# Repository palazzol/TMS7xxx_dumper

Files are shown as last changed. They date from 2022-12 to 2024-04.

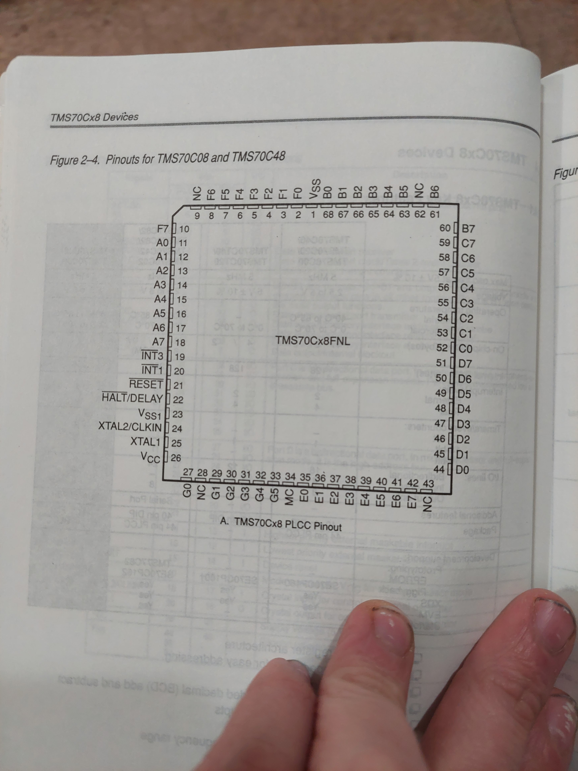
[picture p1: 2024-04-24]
images/latest databook excerpts/20230110_172906.jpg

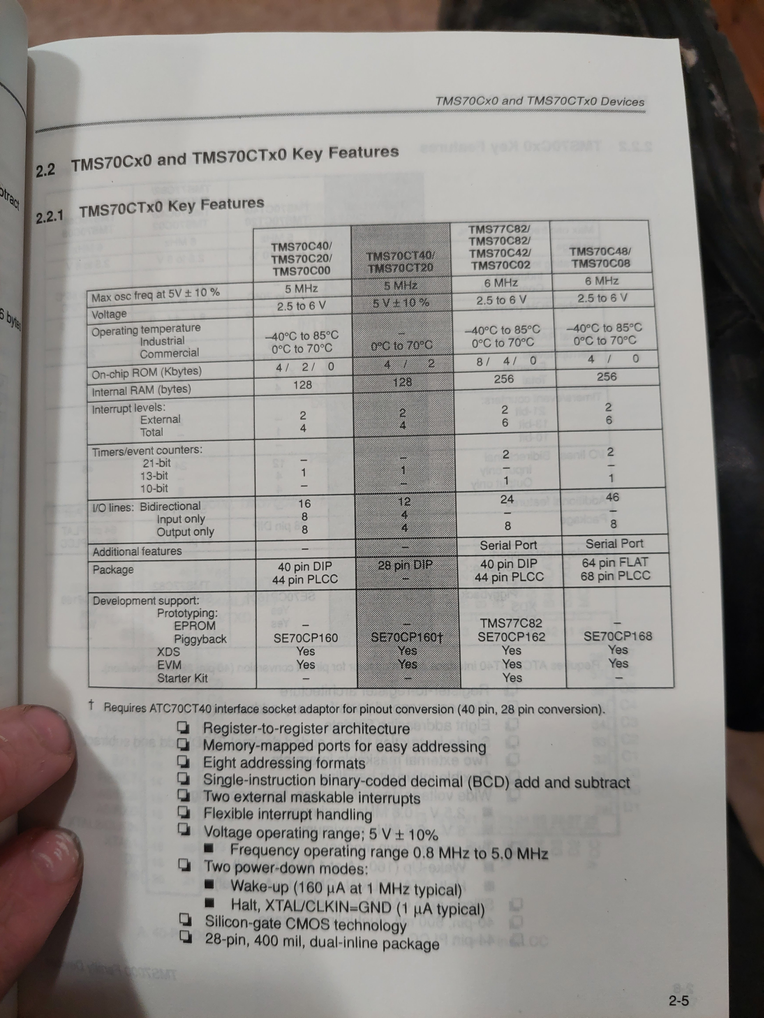
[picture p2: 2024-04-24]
images/latest databook excerpts/20230110_172813.jpg

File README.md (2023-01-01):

# Internal ROM dumper for TMS7xxx series chips

Texas Instruments made a series of chips based on the TMS7000 microprocessor, which can contain internal programs in mask ROM.
General Instrument / Microchip made versions of these chips as well (PIC7000 series).

In addition, at least one commercial IC with a different label is actually one of these internally.
For example, the CTS256A-AL2, which was sold at Radio Shack, is actually a PIC7041.

This design supports all known chips in the series, including:
PIC70XX, TMS70XX, TMS70XXX, TMS77XX, TMS70CXX, and TMS77CXX

This project uses some external code to dump the normally hidden mask ROM, and feed it to a host PC.
In addition, it can identify the type of chip by determining the following parameters:
- RAM size
- ROM size
- Presence of Serial Port
- Process (NMOS or CMOS)

# Instructions:

- Program a 4K 2732-compatible EPROM or FLASH chip with the dumper.bin (Trojan program)
- Program the Arduino Nano with the sketch dumper7k.ino
- Connect via serial terminal, baud rate 115200, 8N1.
- Follow the instructions on screen to identify the chip type and dump any internal rom as a Motorola S-Record format file to the screen
- Save S-Record lines to a .s19 file
- Convert file to binary using srec_cat, or similar tool:

`srec_cat -o <filename>.bin -Binary <filename>.s19`

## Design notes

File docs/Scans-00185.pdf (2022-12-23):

This Material Copyrighted By Its Respective Manufacturer

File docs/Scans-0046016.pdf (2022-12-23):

This Material Copyrighted By Its Respective Manufacturer

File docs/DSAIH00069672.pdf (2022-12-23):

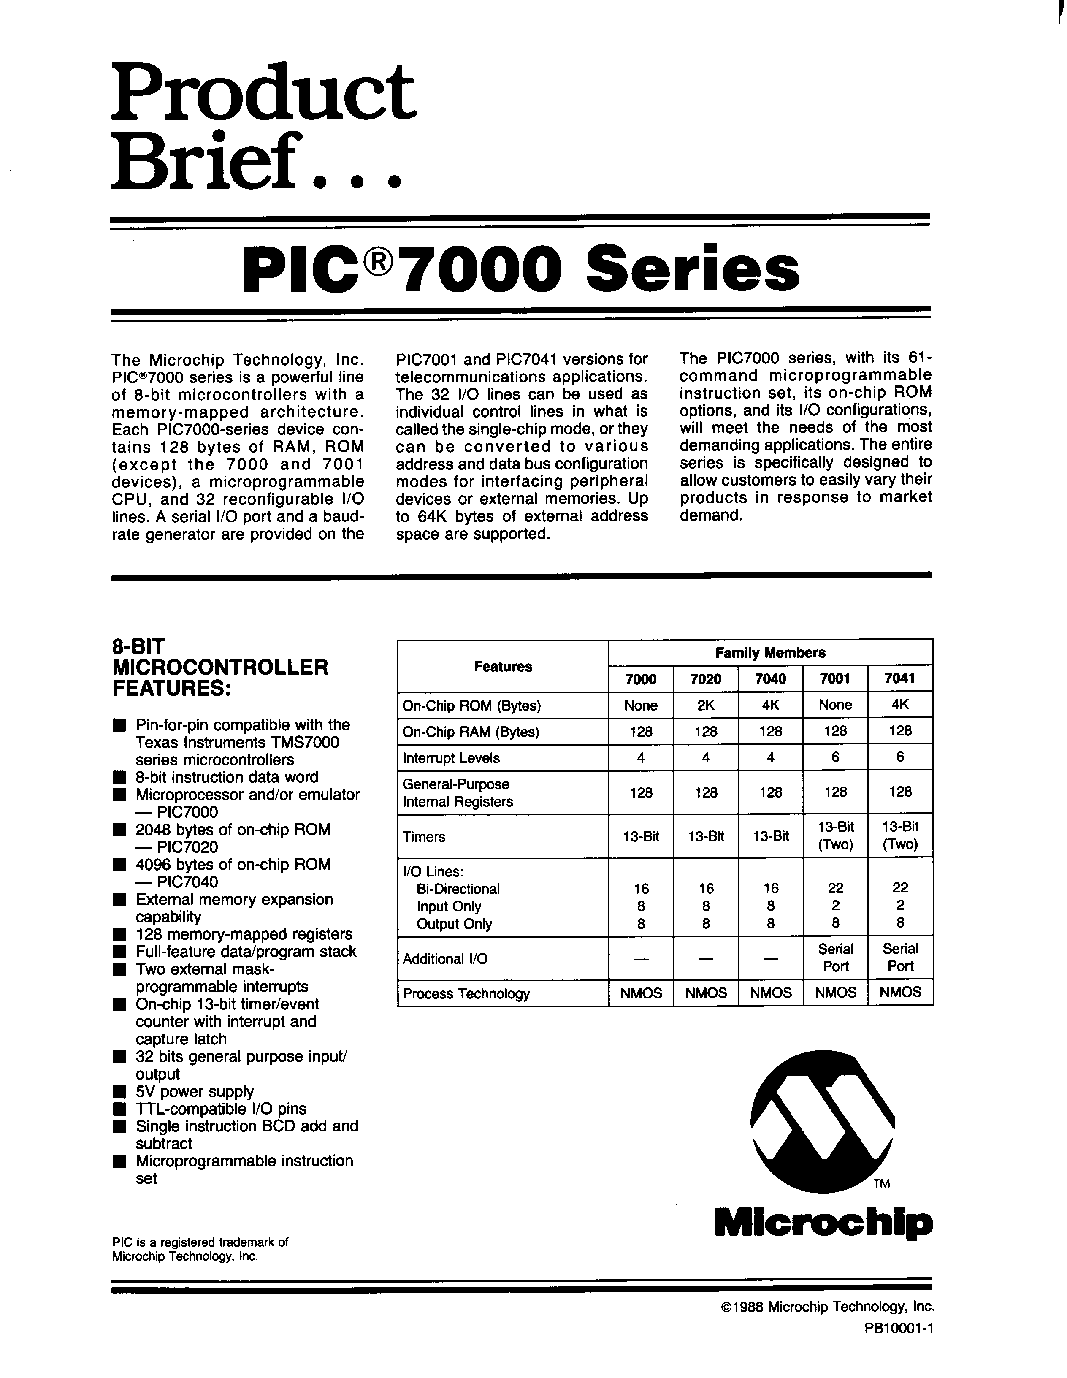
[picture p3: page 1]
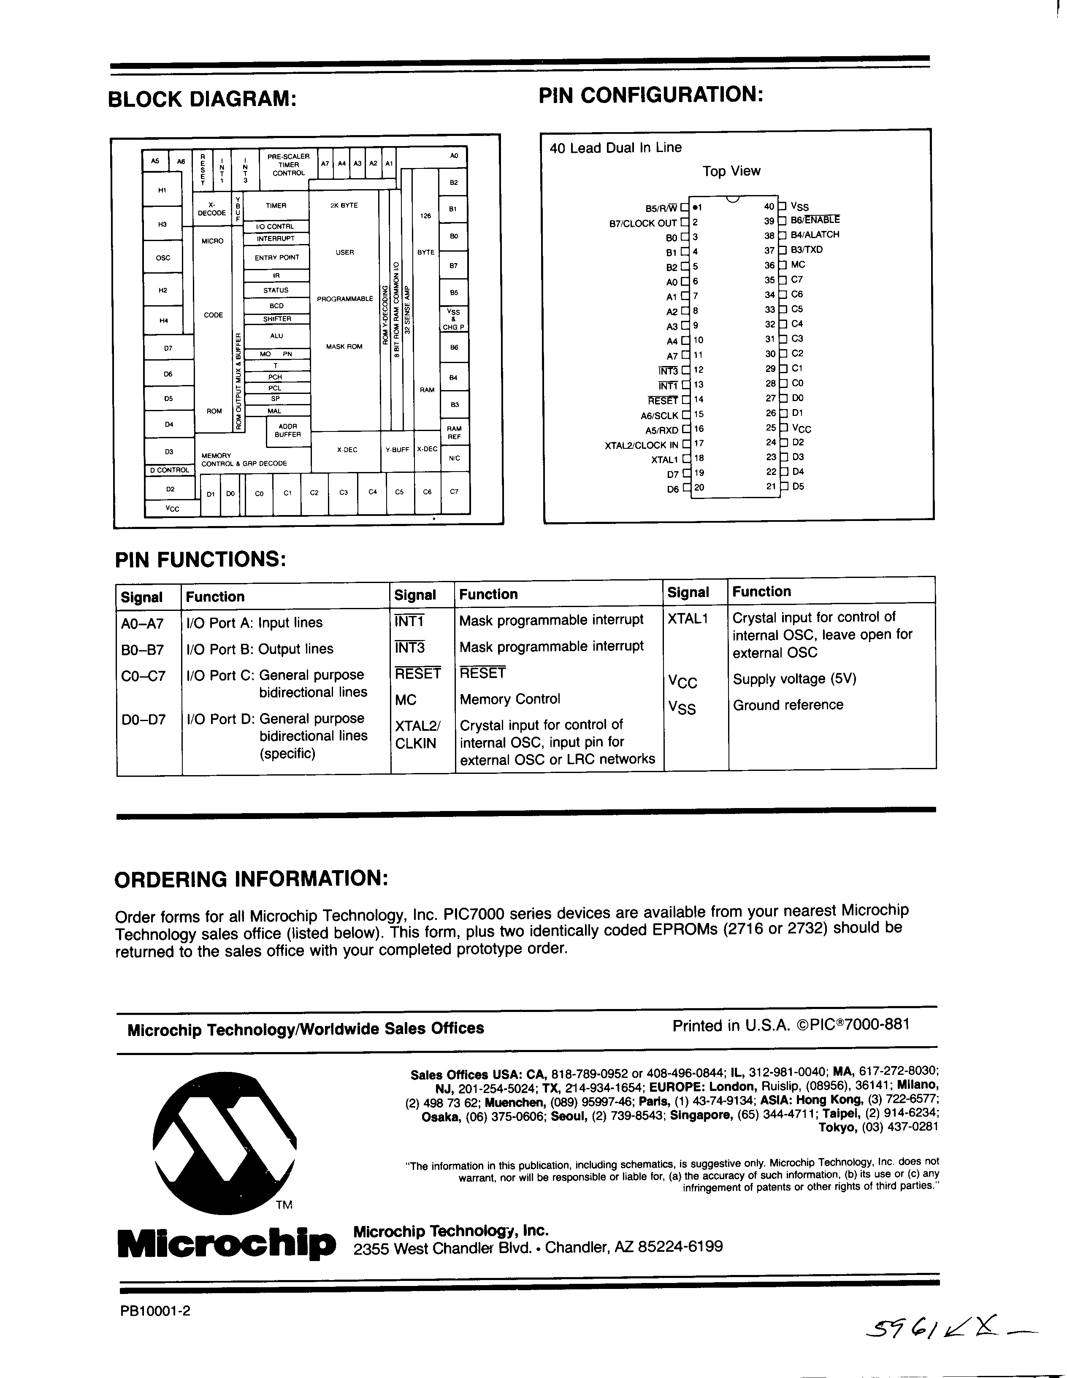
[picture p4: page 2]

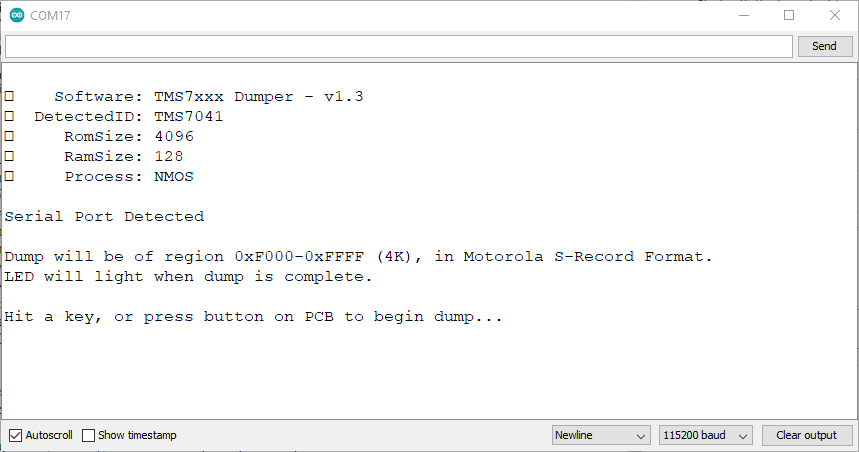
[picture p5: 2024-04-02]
images/screenshots/javaw_dSHYDibQ03.png

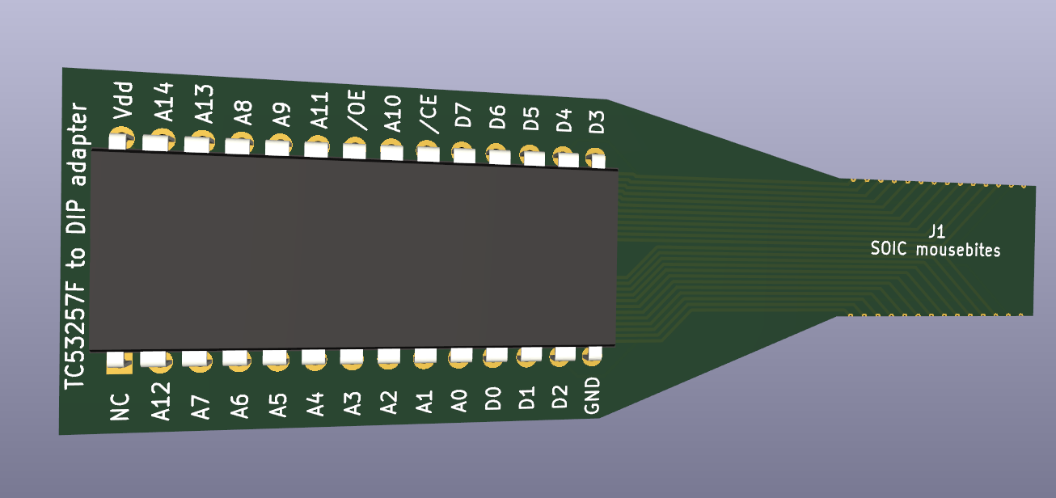
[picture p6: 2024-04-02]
images/screenshots/kicad_d6GzBPXKrp.png

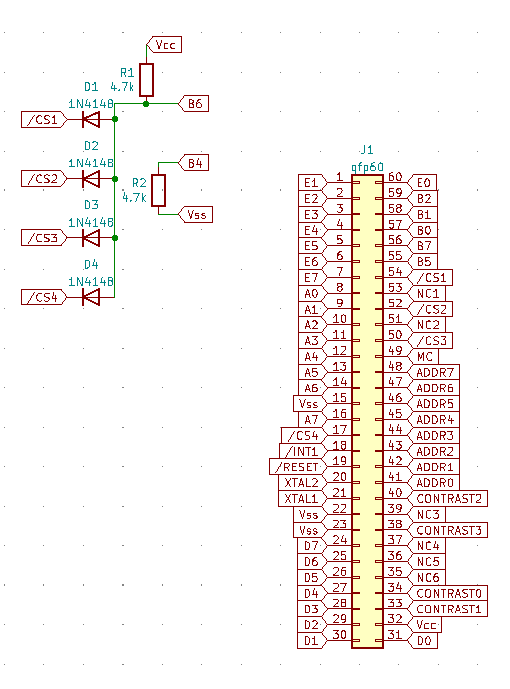
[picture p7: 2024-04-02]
images/screenshots/kicad_FwNVgi2S0T.png

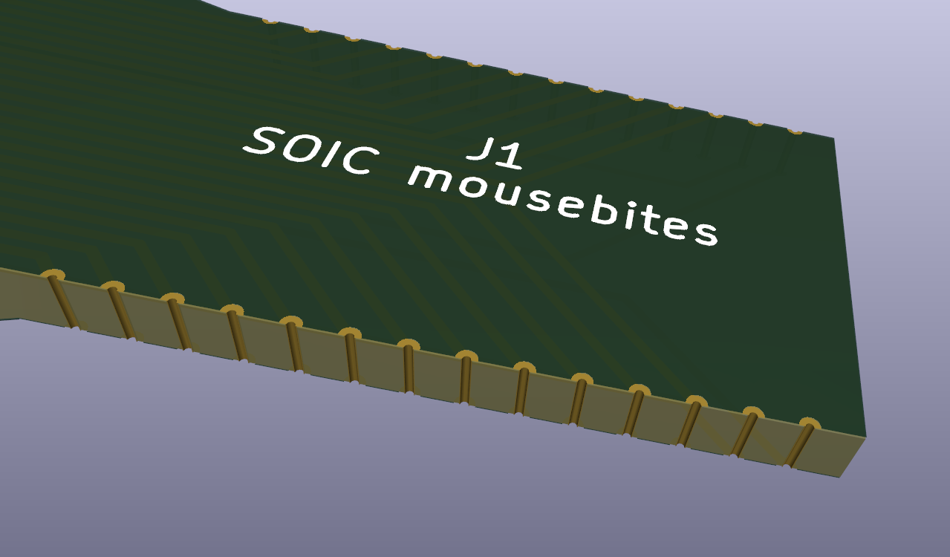
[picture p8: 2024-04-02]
images/screenshots/kicad_MDfL1O8tV8.png

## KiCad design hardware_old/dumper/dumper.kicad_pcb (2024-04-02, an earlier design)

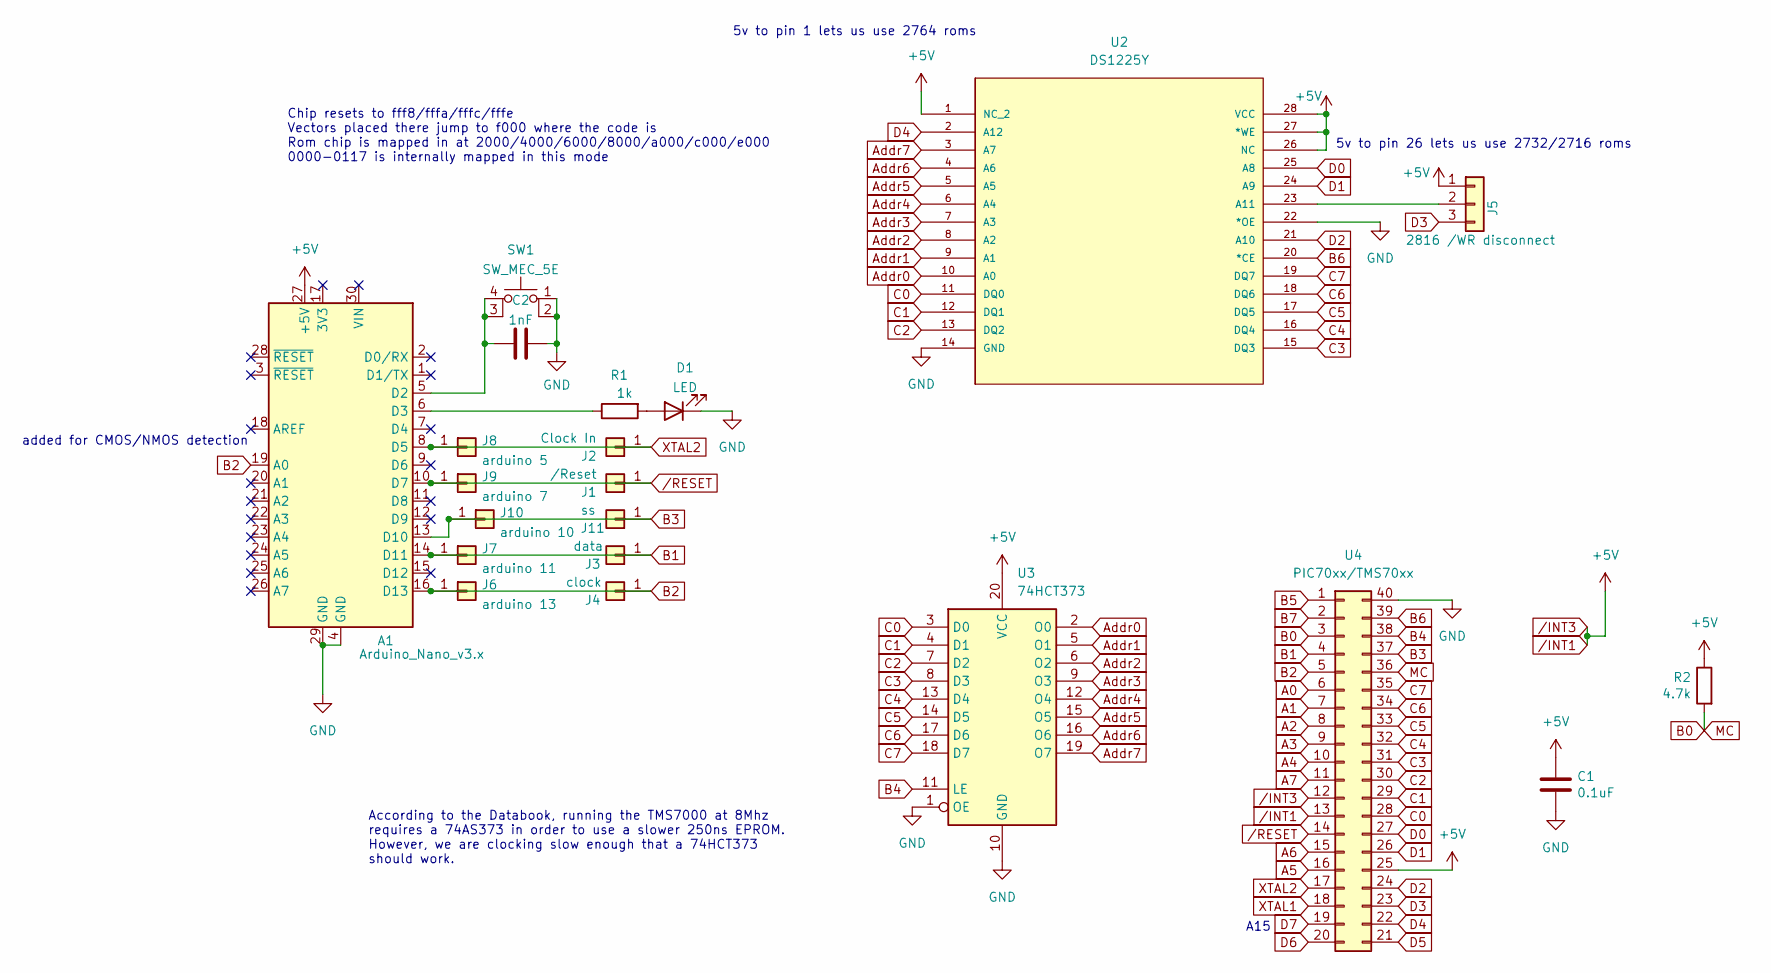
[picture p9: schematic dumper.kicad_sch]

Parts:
A1: Arduino_Nano_v3.x; Arduino_Nano
C1: 0.1uF; C_Axial_L3.8mm_D2.6mm_P7.50mm_Horizontal
C2: 1nF; C_Axial_L3.8mm_D2.6mm_P7.50mm_Horizontal
D1: LED; LED_D5.0mm
J1: /Reset; PinHeader_1x01_P2.54mm_Vertical
J2: Clock In; PinHeader_1x01_P2.54mm_Vertical
J3: data; PinHeader_1x01_P2.54mm_Vertical
J4: clock; PinHeader_1x01_P2.54mm_Vertical
J5: 2816 /WR disconnect; PinHeader_1x03_P2.54mm_Vertical
J6: arduino 13; PinHeader_1x01_P2.54mm_Vertical
J7: arduino 11; PinHeader_1x01_P2.54mm_Vertical
J8: arduino 5; PinHeader_1x01_P2.54mm_Vertical
J9: arduino 7; PinHeader_1x01_P2.54mm_Vertical
J10: arduino 10; PinHeader_1x01_P2.54mm_Vertical
J11: ss; PinHeader_1x01_P2.54mm_Vertical
R1: 1k; R_Axial_DIN0207_L6.3mm_D2.5mm_P2.54mm_Vertical
R2: 4.7k; R_Axial_DIN0207_L6.3mm_D2.5mm_P2.54mm_Vertical
SW1: SW_MEC_5E; SW_TH_Tactile_Omron_B3F-10xx
U2: DS1225Y; 21-0245A_28; MANUFACTURER_PART_NUMBER DS1225Y150+
U3: 74HCT373; DIP-20_W7.62mm
U4: PIC70xx/TMS70xx; DIP-40_W15.24mm

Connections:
A0: U4.6
A1: U4.7
A2: U4.8
A3: U4.9
A4: U4.10
A5: U4.16
A6: U4.15
A7: U4.11
Addr0: U2.10 (A0), U3.2 (O0)
Addr1: U2.9 (A1), U3.5 (O1)
Addr2: U2.8 (A2), U3.6 (O2)
Addr3: U2.7 (A3), U3.9 (O3)
Addr4: U2.6 (A4), U3.12 (O4)
Addr5: U2.5 (A5), U3.15 (O5)
Addr6: U2.4 (A6), U3.16 (O6)
Addr7: U2.3 (A7), U3.19 (O7)
B0: R2.2, U4.3, U4.36
B1: A1.14 (D11), J3.1, J7.1, U4.4
B2: A1.16 (D13), A1.19 (A0), J4.1, J6.1, U4.5
B3: A1.13 (D10), J10.1, J11.1, U4.37
B4: U3.11 (LE), U4.38
B5: U4.1
B6: U2.20 (*CE), U4.39
B7: U4.2
C0: U2.11 (DQ0), U3.3 (D0), U4.28
C1: U2.12 (DQ1), U3.4 (D1), U4.29
C2: U2.13 (DQ2), U3.7 (D2), U4.30
C3: U2.15 (DQ3), U3.8 (D3), U4.31
C4: U2.16 (DQ4), U3.13 (D4), U4.32
C5: U2.17 (DQ5), U3.14 (D5), U4.33
C6: U2.18 (DQ6), U3.17 (D6), U4.34
C7: U2.19 (DQ7), U3.18 (D7), U4.35
D0: U2.25 (A8), U4.27
D1: U2.24 (A9), U4.26
D2: U2.21 (A10), U4.24
D3: J5.3, U4.23
D4: U2.2 (A12), U4.22
D5: U4.21
D6: U4.20
D7: U4.19
GND: A1.4 (GND), A1.29 (GND), C1.2, C2.1, D1.1 (K), SW1.1, SW1.2, U2.14 (GND), U2.22 (*OE), U3.1 (OE), U3.10 (GND), U4.40
unnamed: A1.5 (D2), C2.2, SW1.3 (K), SW1.4 (A)
unnamed: A1.6 (D3), R1.1
unnamed: D1.2 (A), R1.2
unnamed: J5.2, U2.23 (A11)
XTAL1: U4.18
XTAL2: A1.8 (D5), J2.1, J8.1, U4.17
/INT1: A1.27 (+5V), C1.1, J5.1, R2.1, U2.1 (NC_2), U2.26 (NC), U2.27 (*WE), U2.28 (VCC), U3.20 (VCC), U4.12, U4.13, U4.25
/RESET: A1.10 (D7), J1.1, J9.1, U4.14

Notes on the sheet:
According to the Databook, running the TMS7000 at 8Mhz requires a 74AS373 in order to use a slower 250ns EPROM. However, we are clocking slow enough that a 74HCT373 should work.
added for CMOS/NMOS detection
5v to pin 26 lets us use 2732/2716 roms
5v to pin 1 lets us use 2764 roms
Chip resets to fff8/fffa/fffc/fffe Vectors placed there jump to f000 where the code is Rom chip is mapped in at 2000/4000/6000/8000/a000/c000/e000 0000-0117 is internally mapped in this mode
A15

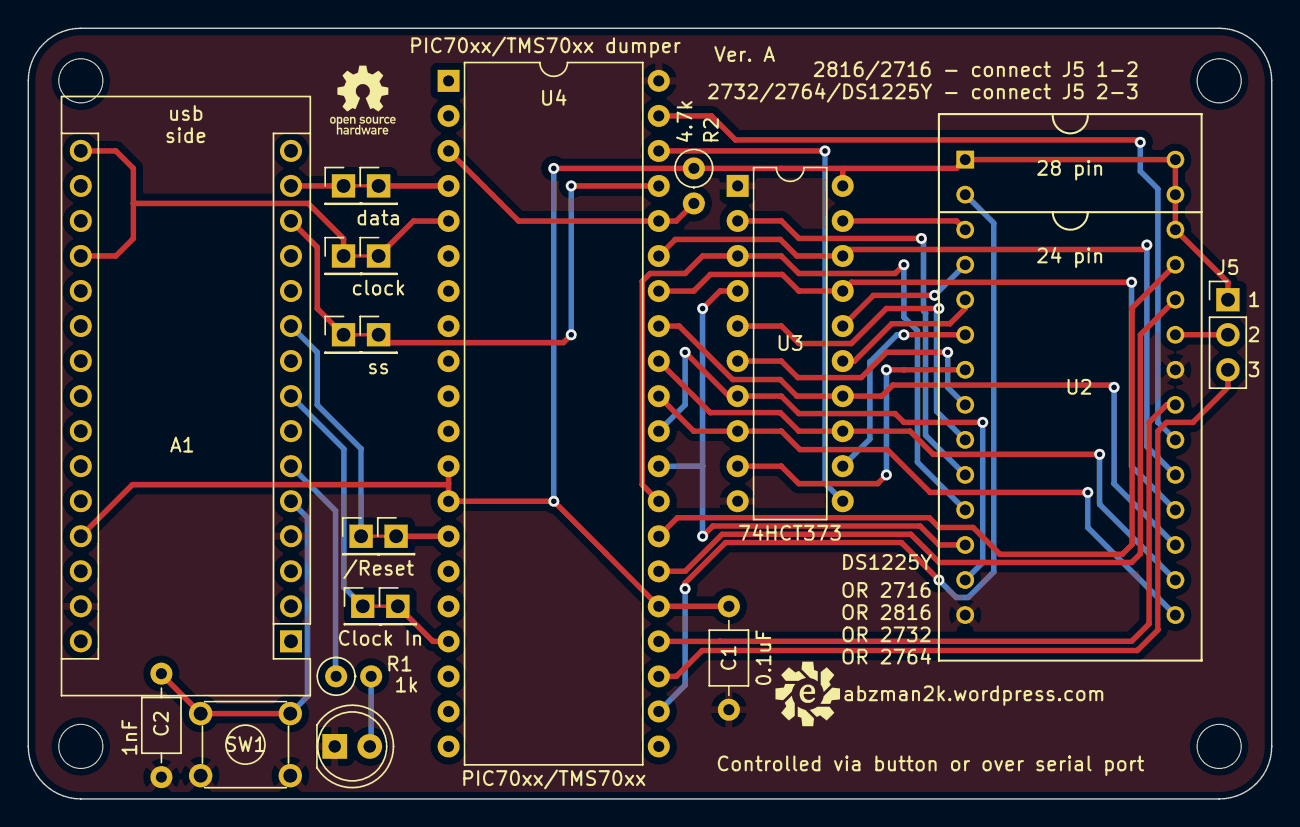
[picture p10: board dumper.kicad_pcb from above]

Board: 2 copper layers, 90.2 x 55.9 mm, 21 parts (0 on the bottom side), 35 nets.

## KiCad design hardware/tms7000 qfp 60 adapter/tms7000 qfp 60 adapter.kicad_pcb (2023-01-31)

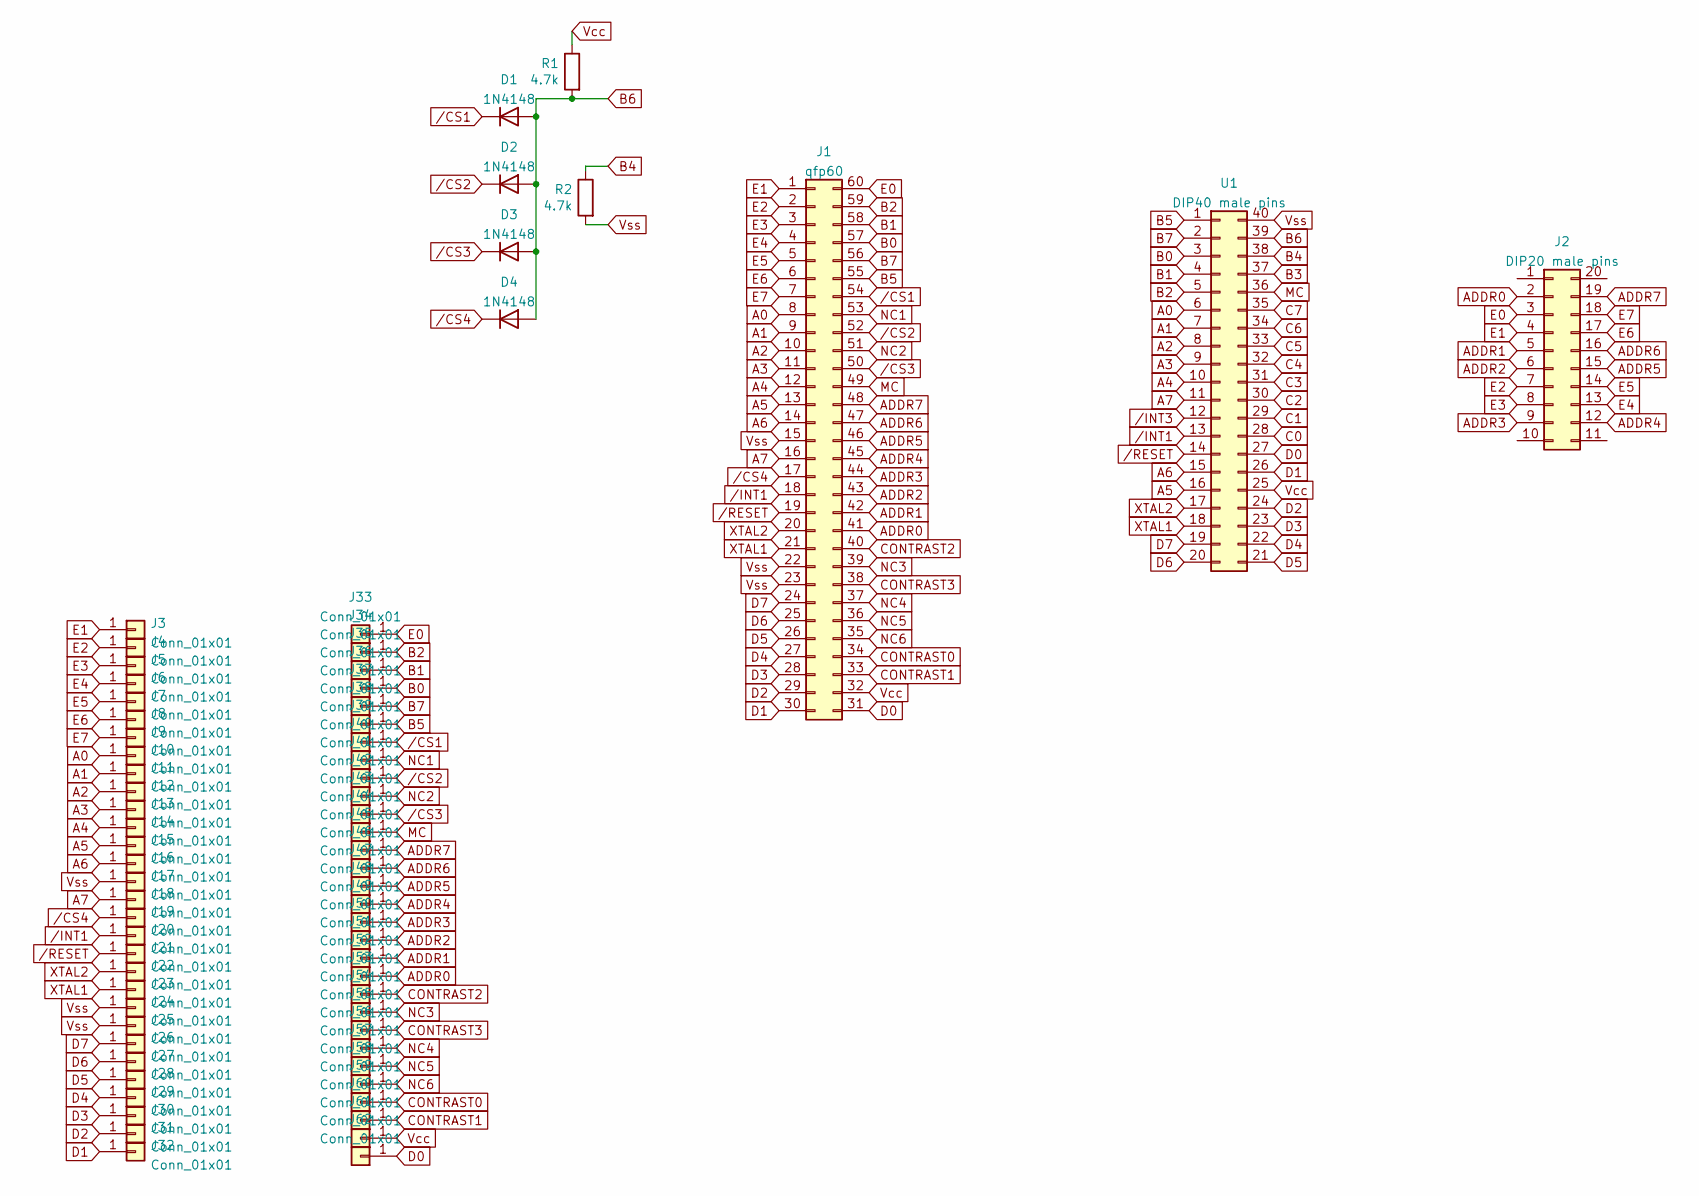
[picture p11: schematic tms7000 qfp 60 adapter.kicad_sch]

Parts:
D1, D2, D3, D4: 1N4148; D_DO-35_SOD27_P2.54mm_Vertical_AnodeUp
J1: qfp60; MQFP-60_P0.8mm
J2: DIP20 male pins; DIP-20_W7.62mm
J3, J4, J5, J6, J7, J8, J9, J10, J11, J12, J13, J14, J15, J16, J17, J18, J19, J20, J21, J22, J23, J24, J25, J26, J27, J28, J29, J30, J31, J32, J33, J34, J35, J36, J37, J38, J39, J40, J41, J42, J43, J44, J45, J46, J47, J48, J49, J50, J51, J52, J53, J54, J55, J56, J57, J58, J59, J60, J61, J62: Conn_01x01; PinHeader_1x01_P2.54mm_Vertical
R1, R2: 4.7k; R_Axial_DIN0207_L6.3mm_D2.5mm_P2.54mm_Vertical
U1: DIP40 male pins; DIP-40_W15.24mm

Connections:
A0: J1.8, J10.1, U1.6
A1: J1.9, J11.1, U1.7
A2: J1.10, J12.1, U1.8
A3: J1.11, J13.1, U1.9
A4: J1.12, J14.1, U1.10
A5: J1.13, J15.1, U1.16
A6: J1.14, J16.1, U1.15
A7: J1.16, J18.1, U1.11
ADDR0: J1.41, J2.2, J52.1
ADDR1: J1.42, J2.5, J51.1
ADDR2: J1.43, J2.6, J50.1
ADDR3: J1.44, J2.9, J49.1
ADDR4: J1.45, J2.12, J48.1
ADDR5: J1.46, J2.15, J47.1
ADDR6: J1.47, J2.16, J46.1
ADDR7: J1.48, J2.19, J45.1
B0: J1.57, J36.1, U1.3
B1: J1.58, J35.1, U1.4
B2: J1.59, J34.1, U1.5
B3: U1.37
B4: R2.1, U1.38
B5: J1.55, J38.1, U1.1
B6: D1.2 (A), D2.2 (A), D3.2 (A), D4.2 (A), R1.2, U1.39
B7: J1.56, J37.1, U1.2
C0: U1.28
C1: U1.29
C2: U1.30
C3: U1.31
C4: U1.32
C5: U1.33
C6: U1.34
C7: U1.35
CONTRAST0: J1.34, J59.1
CONTRAST1: J1.33, J60.1
CONTRAST2: J1.40, J53.1
CONTRAST3: J1.38, J55.1
D0: J1.31, J62.1, U1.27
D1: J1.30, J32.1, U1.26
D2: J1.29, J31.1, U1.24
D3: J1.28, J30.1, U1.23
D4: J1.27, J29.1, U1.22
D5: J1.26, J28.1, U1.21
D6: J1.25, J27.1, U1.20
D7: J1.24, J26.1, U1.19
E0: J1.60, J2.3, J33.1
E1: J1.1, J2.4, J3.1
E2: J1.2, J2.7, J4.1
E3: J1.3, J2.8, J5.1
E4: J1.4, J2.13, J6.1
E5: J1.5, J2.14, J7.1
E6: J1.6, J2.17, J8.1
E7: J1.7, J2.18, J9.1
MC: J1.49, J44.1, U1.36
NC1: J1.53, J40.1
NC2: J1.51, J42.1
NC3: J1.39, J54.1
NC4: J1.37, J56.1
NC5: J1.36, J57.1
NC6: J1.35, J58.1
Vcc: J1.32, J61.1, R1.1, U1.25
Vss: J1.15, J1.22, J1.23, J17.1, J24.1, J25.1, R2.2, U1.40
XTAL1: J1.21, J23.1, U1.18
XTAL2: J1.20, J22.1, U1.17
/CS1: D1.1 (K), J1.54, J39.1
/CS2: D2.1 (K), J1.52, J41.1
/CS3: D3.1 (K), J1.50, J43.1
/CS4: D4.1 (K), J1.17, J19.1
/INT1: J1.18, J20.1, U1.13
/INT3: U1.12
/RESET: J1.19, J21.1, U1.14

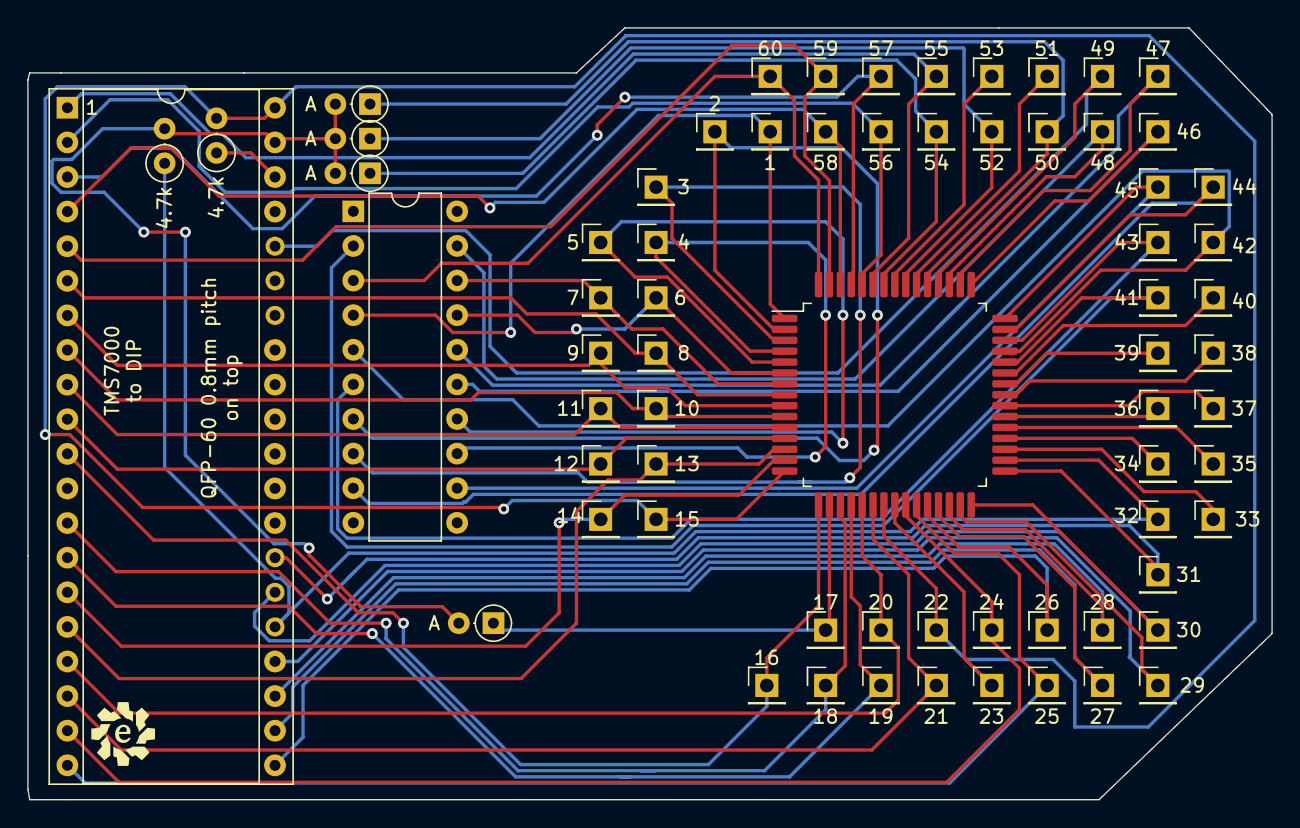
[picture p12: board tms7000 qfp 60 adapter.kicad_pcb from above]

Board: 2 copper layers, 91.3 x 56.6 mm, 69 parts (0 on the bottom side), 60 nets.

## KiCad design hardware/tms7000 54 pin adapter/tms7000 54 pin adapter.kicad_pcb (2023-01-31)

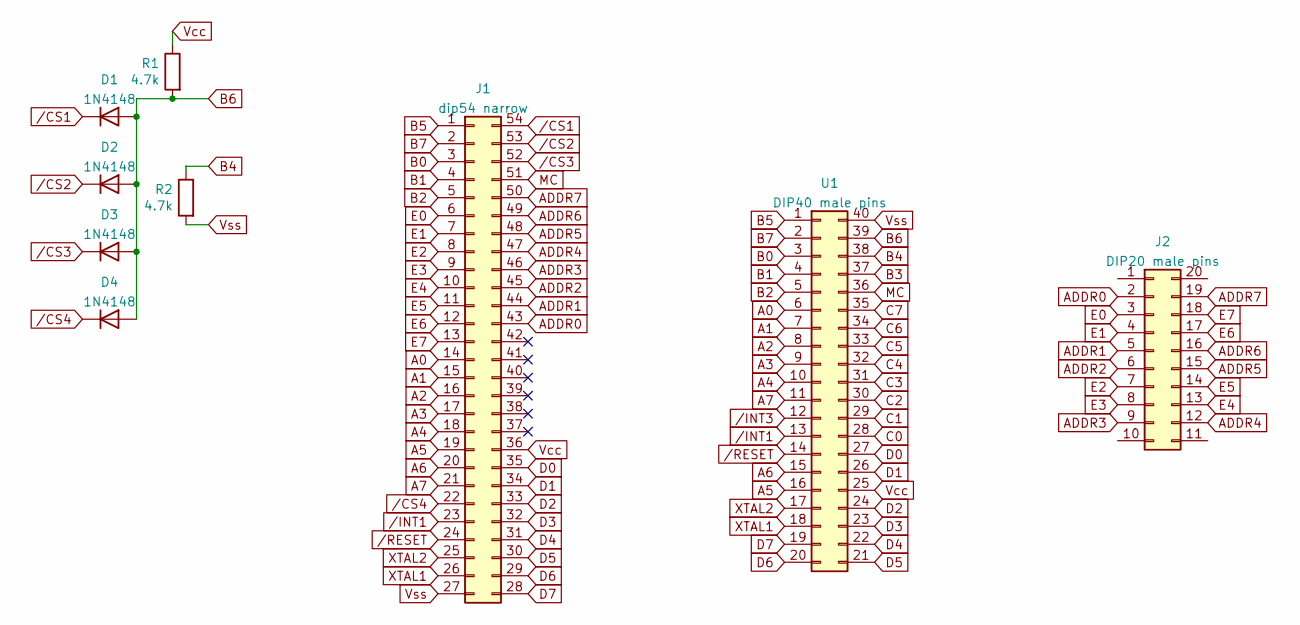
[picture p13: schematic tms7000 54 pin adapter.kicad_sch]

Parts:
D1, D2, D3, D4: 1N4148; D_DO-35_SOD27_P2.54mm_Vertical_AnodeUp
J1: dip54 narrow; DIP 54 1.78mm
J2: DIP20 male pins; DIP-20_W7.62mm
R1, R2: 4.7k; R_Axial_DIN0207_L6.3mm_D2.5mm_P2.54mm_Vertical
U1: DIP40 male pins; DIP-40_W15.24mm

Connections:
A0: J1.14, U1.6
A1: J1.15, U1.7
A2: J1.16, U1.8
A3: J1.17, U1.9
A4: J1.18, U1.10
A5: J1.19, U1.16
A6: J1.20, U1.15
A7: J1.21, U1.11
ADDR0: J1.43, J2.2
ADDR1: J1.44, J2.5
ADDR2: J1.45, J2.6
ADDR3: J1.46, J2.9
ADDR4: J1.47, J2.12
ADDR5: J1.48, J2.15
ADDR6: J1.49, J2.16
ADDR7: J1.50, J2.19
B0: J1.3, U1.3
B1: J1.4, U1.4
B2: J1.5, U1.5
B3: U1.37
B4: R2.1, U1.38
B5: J1.1, U1.1
B6: D1.2 (A), D2.2 (A), D3.2 (A), D4.2 (A), R1.2, U1.39
B7: J1.2, U1.2
C0: U1.28
C1: U1.29
C2: U1.30
C3: U1.31
C4: U1.32
C5: U1.33
C6: U1.34
C7: U1.35
D0: J1.35, U1.27
D1: J1.34, U1.26
D2: J1.33, U1.24
D3: J1.32, U1.23
D4: J1.31, U1.22
D5: J1.30, U1.21
D6: J1.29, U1.20
D7: J1.28, U1.19
E0: J1.6, J2.3
E1: J1.7, J2.4
E2: J1.8, J2.7
E3: J1.9, J2.8
E4: J1.10, J2.13
E5: J1.11, J2.14
E6: J1.12, J2.17
E7: J1.13, J2.18
MC: J1.51, U1.36
Vcc: J1.36, R1.1, U1.25
Vss: J1.27, R2.2, U1.40
XTAL1: J1.26, U1.18
XTAL2: J1.25, U1.17
/CS1: D1.1 (K), J1.54
/CS2: D2.1 (K), J1.53
/CS3: D3.1 (K), J1.52
/CS4: D4.1 (K), J1.22
/INT1: J1.23, U1.13
/INT3: U1.12
/RESET: J1.24, U1.14

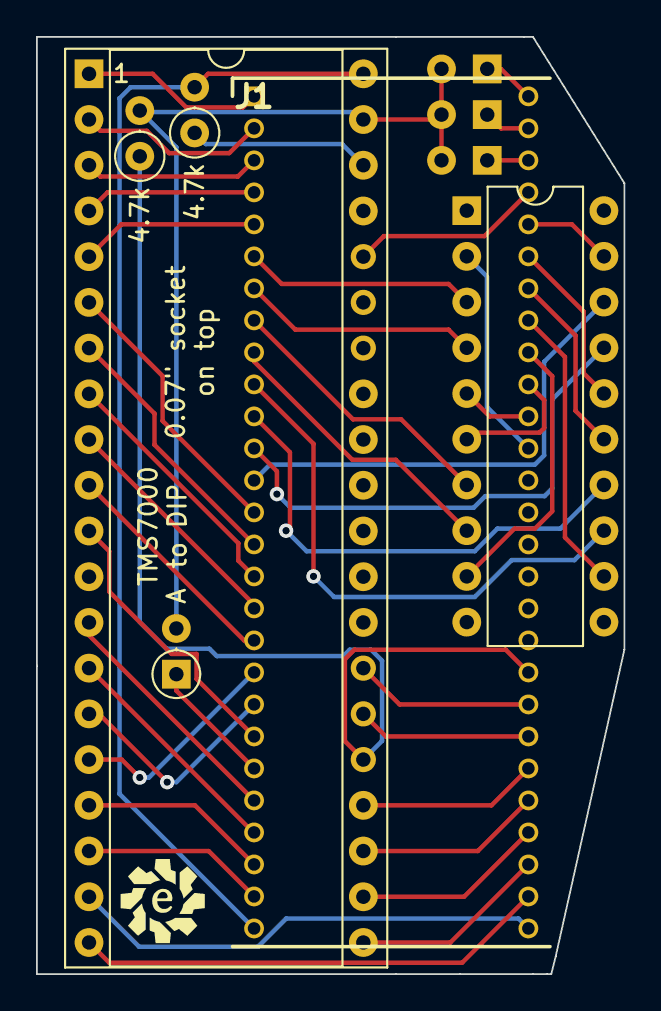
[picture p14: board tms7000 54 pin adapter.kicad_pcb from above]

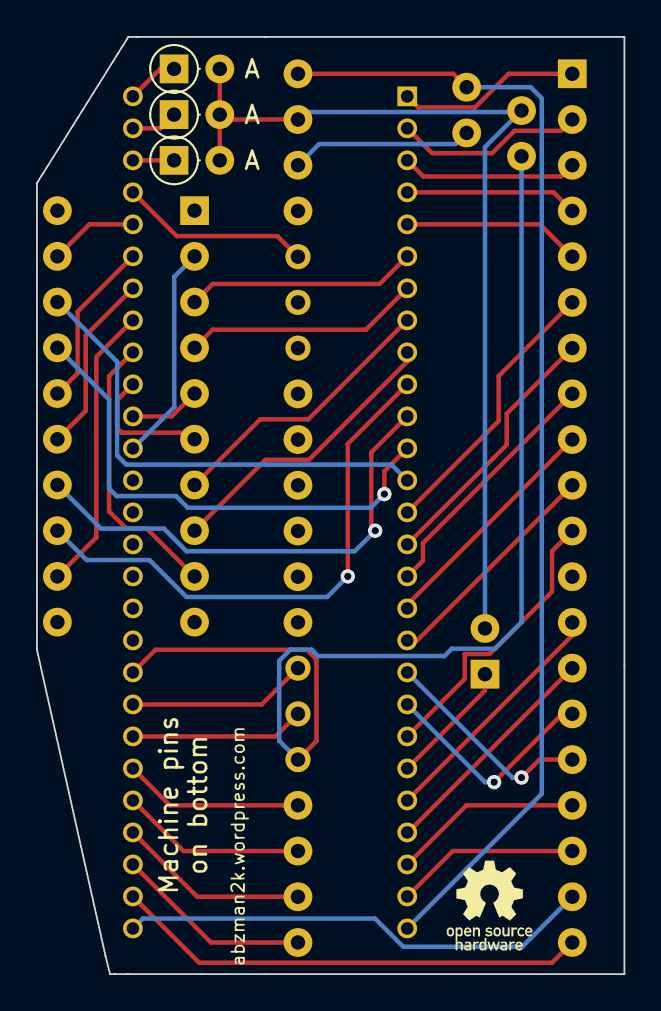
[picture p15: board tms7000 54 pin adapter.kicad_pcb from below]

Board: 2 copper layers, 32.6 x 52.1 mm, 9 parts (3 on the bottom side), 50 nets.

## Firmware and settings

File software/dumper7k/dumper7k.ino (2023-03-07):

// TMS70xx Dumper
//
// Connections:

// Arduino  -  TMS7000
// D2       -> CLKIN
// D8      <-  ADDR/DATA0         
// D9      <-  ADDR/DATA1
// D10     <-  ADDR/DATA2
// D11     <-  ADDR/DATA3
// D4      <-  ADDR/DATA4
// D5      <-  ADDR/DATA5
// D6      <-  ADDR/DATA6
// D7      <-  ADDR/DATA7
// D13      -> MC
// A0      <- ALATCH
// A1      <- R/~W
// A2      <- ~ENABLE
// A3      <- CLKOUT
// A4       -> ~RESET

// Interface to chip
constexpr int PIN_CLKIN   = 2;
constexpr int PIN_AD[8]   = { 8, 9, 10, 11, 4, 5, 6, 7 };
constexpr int PIN_MC      = 13;
constexpr int PIN_ALATCH  = A0;
constexpr int PIN_RnW     = A1;
constexpr int PIN_nENABLE = A2;
constexpr int PIN_CLKOUT  = A3;
constexpr int PIN_nRESET  = A4;
constexpr int PIN_nREAD   = A5;

// UI
constexpr int PIN_BUTTON = A7;
constexpr int PIN_LED    = 3;

#include "SRecWriter.h"

//////////////////////// Global Variables

// Number of bytes received during dump
uint16_t g_count;

// ID Byte
uint8_t g_ID_byte;

// Chip characteristics
String g_number = "Unknown";
uint16_t g_ram_bytes = 0;
uint16_t g_rom_bytes = 0;
bool g_serial_port = false;
bool g_cmos = false;
uint16_t g_dot_count = 0;
bool g_doing_dots = false;

// bus state  - bit0-3
#define BIT_ALATCH  (1 << 0)
#define BIT_RnW     (1 << 1)
#define BIT_nENABLE (1 << 2)
#define BIT_CLKOUT  (1 << 3)
uint8_t g_last_bus_state = 0x0f;
uint8_t g_curr_bus_state = 0x0f;

// Start Vector
uint16_t g_start_vector;

// S19 Format writer component
SRecWriter g_writer;

// State variable
enum {
  STATE_GETTING_ID,
  STATE_WAITING,
  STATE_DUMPING,
  STATE_WAITING2,
} g_state;

// bus actions
typedef enum {
  BUS_ADDR_AVAILABLE,
  BUS_DATA_R_AVAILABLE,
  BUS_DATA_W_AVAILABLE,
  BUS_NOEVENT,
} bus_event_t;

typedef struct {
  bus_event_t bus_event;
  uint8_t     pin_mask_last;
  uint8_t     pin_state_last;
  uint8_t     pin_mask_curr;
  uint8_t     pin_state_curr;
} bus_event_def_t;

void setup() {
  pinMode(PIN_CLKIN, OUTPUT);
  for(int i=0; i<8; i++)
    pinMode(PIN_AD[i], INPUT);
  pinMode(PIN_MC, OUTPUT);
  pinMode(PIN_ALATCH, INPUT);  
  pinMode(PIN_RnW, INPUT);
  pinMode(PIN_nENABLE, INPUT);
  pinMode(PIN_CLKOUT, INPUT);
  pinMode(PIN_nRESET, OUTPUT);
  pinMode(PIN_nREAD, OUTPUT);

  pinMode(PIN_BUTTON, INPUT);
  pinMode(PIN_LED, OUTPUT);

  // Microprocessor mode (external ROM only)
  digitalWrite(PIN_MC, HIGH);
  // Reset pin low
  digitalWrite(PIN_nRESET, LOW);
  // LED off
  digitalWrite(PIN_LED, LOW);
  // Default to Read Mode
  digitalWrite(PIN_nREAD, LOW);

  // Enable serial port
  Serial.begin(115200);
  while (!Serial) {
    ; // wait for serial port to connect. Needed for native USB port only
  }

  goToGettingIDState();
}

// Function to do run one clock cycle
void clockPulse()
{
  static bool s_state = false;

  if (g_doing_dots) {
    g_dot_count++;
    g_dot_count %= 0x1000;
    if (g_dot_count == 0) {
      Serial.print('.');
    }
  }
  
  // Slow version
  if (s_state == false)
  {
    digitalWrite(PIN_CLKIN, LOW);
    s_state = true;
  }
  else
  {
    digitalWrite(PIN_CLKIN, HIGH);
    s_state = false;
  }

  // Faster version
  //PORTD &= ~0x20;
  //delayMicroseconds(2);
  //PORTD |= 0x20;
  //delayMicroseconds(2);

  // Update RnW
  if (digitalRead(PIN_RnW) == LOW)
  {
    digitalWrite(PIN_nREAD, HIGH); // invert
    g_curr_bus_state &= (BIT_RnW ^ 0x0f);
  }
  else
  {
    digitalWrite(PIN_nREAD, LOW); // invert
    g_curr_bus_state |= BIT_RnW;
  }

  // Update ALATCH  
  if (digitalRead(PIN_ALATCH) == LOW)
    g_curr_bus_state &= (BIT_ALATCH ^ 0x0f);
  else
    g_curr_bus_state |= BIT_ALATCH;

  // Update nENABLE
  if (digitalRead(PIN_nENABLE) == LOW)
    g_curr_bus_state &= (BIT_nENABLE ^ 0x0f);
  else
    g_curr_bus_state |= BIT_nENABLE;

  // Update CLKOUT  
  if (digitalRead(PIN_CLKOUT) == LOW)
    g_curr_bus_state &= (BIT_CLKOUT ^ 0x0f);
  else
    g_curr_bus_state |= BIT_CLKOUT;
}

bus_event_t processBusState()
{
  const bus_event_def_t event_def[] =
  {
    { BUS_ADDR_AVAILABLE,   BIT_ALATCH, 0, 
                            BIT_ALATCH, BIT_ALATCH },
    { BUS_DATA_R_AVAILABLE, BIT_nENABLE | BIT_RnW | BIT_CLKOUT, 0 | BIT_RnW | BIT_CLKOUT,  
                            BIT_nENABLE | BIT_RnW | BIT_CLKOUT, 0 | BIT_RnW |          0 },
    { BUS_DATA_W_AVAILABLE, BIT_nENABLE | BIT_RnW | BIT_CLKOUT, 0 |       0 | BIT_CLKOUT,  
                            BIT_nENABLE | BIT_RnW | BIT_CLKOUT, 0 |       0 |          0 },
    { BUS_NOEVENT,          0x00, 0x00, 
                            0x00, 0x00 },
  };

  uint8_t i=0;
  bool done = false;
  bus_event_t bus_event = BUS_NOEVENT;
  do
  {
    bus_event = event_def[i].bus_event;
    uint8_t last_trigger = g_last_bus_state & event_def[i].pin_mask_last;
    uint8_t curr_trigger = g_curr_bus_state & event_def[i].pin_mask_curr;
    if ((last_trigger == event_def[i].pin_state_last) &&
        (curr_trigger == event_def[i].pin_state_curr))
      break;
    i++;
  } while (bus_event != BUS_NOEVENT);
  g_last_bus_state = g_curr_bus_state;
  return bus_event;
}

void printHeader()
{
  // Process the ID Byte
  processIDByte();

  // Print sequence of parameters
  Serial.print(char(0x01));
  Serial.print(  "  DetectedID: ");
  Serial.println(g_number);

  Serial.print(char(0x01));
  Serial.print(  "     RomSize: ");
  Serial.println(g_rom_bytes);

  Serial.print(char(0x01));
  Serial.print(  "     RamSize: ");
  Serial.println(g_ram_bytes);

  Serial.print(char(0x01));
  Serial.print(  "     Process: ");
  if (g_cmos)
  {
    Serial.println("CMOS");
  }
  else
  {
    Serial.println("NMOS");
  }

  Serial.println();
  if (g_serial_port)
    Serial.println("Serial Port Detected");

  if (g_ID_byte == 0xb || g_ID_byte == 0x13)
  {
    if (g_cmos)
      Serial.println("Note: Could be TMS77Cxx if part has a UV window (possibly under a sticker)");
    else
      Serial.println("Note: Could be TMS77xx if part has a UV window (possibly under a sticker)");
  }

  if (!g_cmos)
    if (g_ID_byte == 0x0 || g_ID_byte == 0x01 || g_ID_byte == 0x04 || g_ID_byte == 0x08 || g_ID_byte == 0x09)
      Serial.println("Note: Could be a PIC70XX");

  if (g_rom_bytes == 0x4000)
    Serial.println("Note: Piggyback part, record info about inserted chip.");

  Serial.println();

  //Serial.print("ID Byte: 0x");
  //Serial.println(g_ID_byte, HEX);
  //Serial.println();

  if (g_rom_bytes > 0)
  {
    Serial.print("Dump will be of region ");
    if (g_rom_bytes == 0x0800)
      Serial.print("0xF800-0xFFFF (2K)");
    if (g_rom_bytes == 0x1000)
      Serial.print("0xF000-0xFFFF (4K)");
    if (g_rom_bytes == 0x2000)
      Serial.print("0xE000-0xFFFF (8K)");
    if (g_rom_bytes == 0x3000)
      Serial.print("0xD000-0xFFFF (12K)");
    if (g_rom_bytes == 0x4000)
      Serial.print("0xC000-0xFFFF (16K)");
    Serial.println(", in Motorola S-Record Format.");

    Serial.println("LED will light when dump is complete.");
    Serial.println();
    Serial.println("Hit a key, or press button on PCB to begin dump...");
  }
  else
  {
    Serial.println("No Internal ROM to dump.");
    Serial.println();
    Serial.println("Hit a key, or press button on PCB to restart identification...");
  }
}

void goToGettingIDState()
{
  // Clear keyboard buffer
  while (Serial.available())
    Serial.read();

  // wait for key release
  while (analogRead(PIN_BUTTON) < 512);
  
  // Reset pin low
  digitalWrite(PIN_nRESET, LOW);
  // LED off
  digitalWrite(PIN_LED, LOW);

  // Clock some while reset
  for (int i = 0; i < 200; i++) {
    clockPulse();
  }

  // Check for process here
  //Do not touch the board when detecting process, it can erroneously read as CMOS
  delay(100);
  if (analogRead(PIN_CLKOUT) > 950) //determined with a few chips on this platform (arduino nano)
    g_cmos = true;

  Serial.println();
  Serial.print(char(0x01));
  Serial.println("    Software: TMS7xxx Dumper - v1.3");
  Serial.println();

  Serial.print("Analyzing IC...");
  g_doing_dots = true;
    
  // Reset pin high
  digitalWrite(PIN_nRESET, HIGH);

  g_count = 0;
  g_ID_byte = 0;
  g_state = STATE_GETTING_ID;
}

void processIDByte()
{
  if (g_ID_byte & 0x01)
    g_serial_port = true;
  else
    g_serial_port = false;
  
  if (g_ID_byte & 0x02)
    g_ram_bytes = 0x100;
  else
    g_ram_bytes = 0x80;
  g_rom_bytes = ((g_ID_byte & 0x3c) >> 2) * 0x0800;

  switch (g_ID_byte) {
    case 0x00:
      if (g_cmos)
        g_number = "TMS70C00";
      else
        g_number = "TMS7000"; // could be a PIC
      break;
    case 0x01:
      if (g_cmos)
        g_number = "TMS70C01";
      else
        g_number = "TMS7001"; // could be a PIC
      break;
    case 0x02:
      if (g_cmos)
        g_number = "Unknown_TMS70C0x";
      else
        g_number = "Unknown_TMS700x";
      break;
    case 0x03:
      if (g_cmos)
        g_number = "TMS70C02";
      else
        g_number = "TMS7002";
      break;
    case 0x04:
      if (g_cmos)
        g_number = "TMS70C20";
      else
        g_number = "TMS7020"; // could be a PIC
      break;
    case 0x05:
      if (g_cmos)
        g_number = "TMS70C21";
      else
        g_number = "TMS7021";
      break;
    case 0x06:
      if (g_cmos)
        g_number = "Unknown_TMS70C2x";
      else
        g_number = "Unknown_TMS702x";
      break;
    case 0x07:
      if (g_cmos)
        g_number = "TMS70C22";
      else
        g_number = "TMS7022";
      break;
    case 0x08:
      if (g_cmos)
        g_number = "TMS70C40";
      else
        g_number = "TMS7040"; // could be a PIC
      break;
    case 0x09:
      if (g_cmos)
        g_number = "TMS70C41";
      else
        g_number = "TMS7041"; // could be a PIC
      break;
    case 0x0a:
      if (g_cmos)
        g_number = "Unknown_TMS70C4x";
      else
        g_number = "Unknown_TMS704x";
      break;
    case 0x0b:
      if (g_cmos)
        g_number = "TMS70C42"; // could be a 77C42 if it has a UV window
      else
        g_number = "TMS7042"; // could be a 7742 if it has a UV window
      break;
    case 0x0c:  // 6K ROM?
    case 0x0d:  // 6K ROM?
    case 0x0e:  
    case 0x0f:  // 6K ROM?
      if (g_cmos)
        g_number = "Unknown_TMS70Cxx";
      else
        g_number = "Unknown_TMS70xx";
      break;
    case 0x10:
      if (g_cmos)
        g_number = "TMS70C80";
      else
        g_number = "Unknown_TMS7080";
      break;
    case 0x11:
      if (g_cmos)
        g_number = "TMS70C81";
      else
        g_number = "Unknown_TMS7081";
      break;
    case 0x12:
      if (g_cmos)
        g_number = "Unknown_TMS70C8x";
      else
        g_number = "Unknown_TMS708x";
      break;
    case 0x13:
      if (g_cmos)
        g_number = "TMS70C82"; // could be a 77C82 if it has a UV window
      else
        g_number = "Unknown_TMS7082";
      break;
    case 0x14:  // 10K ROM?
    case 0x15:  // 10K ROM?
    case 0x16:
    case 0x17:  // 10K ROM?
      if (g_cmos)
        g_number = "Unknown_TMS70Cxx";
      else
        g_number = "Unknown_TMS70xx";
      break;
    case 0x18:
      if (g_cmos)
        g_number = "Unknown_TMS70C120";
      else
        g_number = "TMS70120";
      break;
    case 0x19:
      if (g_cmos)
        g_number = "Unknown_TMS70C121";
      else
        g_number = "TMS70121";
      break;
    case 0x1a:
      if (g_cmos)
        g_number = "Unknown_TMS70C12x";
      else
        g_number = "Unknown_TMS7012x";
    break;
    case 0x1b:
      if (g_cmos)
        g_number = "Unknown_TMS70C122";
      else
        g_number = "TMS70122";
      break;    
    case 0x1c:  // 14K ROM?
    case 0x1d:  // 14K ROM?
    case 0x1e:
    case 0x1f:  // 14K ROM?
      if (g_cmos)
        g_number = "Unknown_TMS70Cxxx";
      else
        g_number = "Unknown_70xxx";
      break;
    case 0x20:
      if (g_cmos)
        g_number = "SE70CP160"; // Piggyback
      else
        g_number = "Unknown_SE70P160"; // Piggyback
      break;
    case 0x21:
      if (g_cmos)
        g_number = "SE70CP161"; // Piggyback
      else
        g_number = "SE70P161"; // Piggyback
      break;
    case 0x22:
      if (g_cmos)
        g_number = "Unknown_SE70CP16x"; // Piggyback
      else
        g_number = "Unknown_SE70P16x"; // Piggyback
      break;
    case 0x23:
      if (g_cmos)
        g_number = "SE70CP162"; // Piggyback
      else
        g_number = "SE70P162"; // Piggyback
      break;
    case 0x043:
      if (g_cmos)
        g_number = "TMS70C08";
      else
        g_number = "Unknown_TMS7008";
      break;
    case 0x04b:
      if (g_cmos)
        g_number = "TMS70C48";
      else
        g_number = "Unknown_TMS7048";
      break;
    case 0x053:
      if (g_cmos)
        g_number = "SE70CP168"; // Piggyback
      else
        g_number = "Unknown_SE70P168";
      break;
    default:
        g_number = "Unknown_ID_0x" + String(g_ID_byte, HEX);
        break;
  }
}

// Grab a byte from the addr/data bus
uint8_t readAddrDataBus()
{
  uint8_t rv = 0x00;
  for(uint8_t i=0;i<8;i++)
  {
    if (digitalRead(PIN_AD[i]) == HIGH)
      rv |= (1 << i);    
  }
  return rv;  
}

void gettingIDStateLogic()
{
  static int s_cycle = 0;
  static uint8_t s_addr = 0;
  static bool s_seen_0x55 = false;

  // Clock pulse
  clockPulse();

  // If no byte, clock some more
  bus_event_t bus_event = processBusState();
  uint8_t bus = readAddrDataBus();
//#define DEBUG_BUS
#ifdef DEBUG_BUS
  for(int i=3;i>=0;i--)
  {
    if ((g_last_bus_state >> i) & 0x01)
      Serial.print('1');
    else
      Serial.print('0');
    Serial.print(' ');
  }
  Serial.print(bus_event);
  Serial.print(' ');
  Serial.print(bus,HEX);
  Serial.print(' ');
  Serial.println(s_cycle);
#endif
  s_cycle++;

//#define DEBUG_BUS_EVENT
#ifdef DEBUG_BUS_EVENT
  if (bus_event != BUS_NOEVENT)
  {
    Serial.print((int)bus_event);
    Serial.print(' ');
    Serial.println(bus,HEX);
  }
#endif

  if (bus_event == BUS_ADDR_AVAILABLE)
  {
    s_addr = readAddrDataBus();
    return;
  }

  if (bus_event != BUS_DATA_W_AVAILABLE)
    return;

  uint8_t data = readAddrDataBus();
  //Serial.print("Write ");
  //Serial.print(data, HEX);
  //Serial.print(" to XX");
  //if (s_addr < 16)
  //  Serial.print('0');
  //Serial.println(s_addr,HEX);

  if (!s_seen_0x55)
  {
    if (data != 0x55)
      return;
    else
    {
      s_seen_0x55 = true;
      digitalWrite(PIN_MC, LOW);
      return;
    }
  }

  g_ID_byte = data;

  s_seen_0x55 = false;
  goToWaitingState();

}

void goToWaitingState()
{
  g_doing_dots = false;
  Serial.println();
  Serial.println();

  // Reset pin low
  digitalWrite(PIN_nRESET, LOW);
  // LED off
  digitalWrite(PIN_LED, LOW);

  // Clock some while reset
  for (int i = 0; i < 200; i++) {
    clockPulse();
  }

  // Print header
  printHeader();

  // Clear keyboard buffer
  while (Serial.available())
    Serial.read();

  // wait for key release
  while (analogRead(PIN_BUTTON) < 512);

  g_writer.reset();
  g_writer.setSerial(Serial);
  g_count = 0;
  g_state = STATE_WAITING;
}

void waitingStateLogic()
{
  // Clock pulse
  clockPulse();

  // If button pushed
  if (analogRead(PIN_BUTTON) < 512)
    if (g_rom_bytes == 0)
      goToGettingIDState();
    else
      goToDumpingState();

  // if key hit
  if (Serial.available())
  {
    uint8_t c = Serial.read();
    if (g_rom_bytes == 0)
      goToGettingIDState();
    else
      goToDumpingState();
  }
}

void goToDumpingState()
{
  // MC high again
  digitalWrite(PIN_MC, HIGH);

  // Reset pin low
  digitalWrite(PIN_nRESET, LOW);
  // LED off
  digitalWrite(PIN_LED, LOW);

  // Clock some while reset
  for (int i = 0; i < 100; i++) {
    clockPulse();
  }

  // Reset pin high
  digitalWrite(PIN_nRESET, HIGH);

  g_count = 0;
  g_state = STATE_DUMPING;
}

void dumpingStateLogic()
{
  static bool s_seen_0x55 = false;

  // Clock pulse
  clockPulse();

  // If no byte, clock some more
  bus_event_t bus_event = processBusState();
  if (bus_event != BUS_DATA_W_AVAILABLE)
    return;

  uint8_t data = readAddrDataBus();
  if (!s_seen_0x55)
  {  
    if (data != 0x55)
      return;
    else  
    {
      s_seen_0x55 = true;
      digitalWrite(PIN_MC, LOW);
      return;
    }
  }

  // Grab the data byte
  uint8_t x = readAddrDataBus();

  if (g_count == 0)
  {
    // This is just the id again, ignore it
    g_count++;
    return;
  }

  // Dump out in S19 format, until we have the full dump
  if (g_count < g_rom_bytes + 1)
  {
    g_writer.addData(x);
    g_count++;
    if (g_count == g_rom_bytes + 1)
    {
      g_writer.finish();
      // LED on
      digitalWrite(PIN_LED, HIGH);
      s_seen_0x55 = false;
      goToWaiting2State();
    }
  }
}

void goToWaiting2State()
{
  // Clear keyboard buffer
  while (Serial.available())
    Serial.read();

  // wait for key release
  while (analogRead(PIN_BUTTON) < 512);

  g_state = STATE_WAITING2;
}

void printDone()
{
  Serial.println();
  Serial.println("Dump Complete.  Restarting...");
}

void waiting2StateLogic()
{
  // If button pushed
  if (analogRead(PIN_BUTTON) < 512)
  {
    printDone();
    goToGettingIDState();
  }

  // if key hit
  if (Serial.available())
  {
    uint8_t c = Serial.read();
    printDone();
    goToGettingIDState();
  }
}

void loop() {

  if (g_state == STATE_WAITING)
  {
    waitingStateLogic();
  }
  else if (g_state == STATE_GETTING_ID)
  {
    gettingIDStateLogic();
  }
  else if (g_state == STATE_DUMPING)
  {
    dumpingStateLogic();
  }
  else { // g_state = STATE_WAITING2
    waiting2StateLogic();
  }
}

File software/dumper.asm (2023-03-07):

;
; Original Code and hardware by Frank Palazzolo
; Code written and working sometime in the early 2000's
; Source Reverse-engineered from Binary(!)
; And updated for standard SPI master interface - 2022-October
; Added Chip ID functions, 2022-November
; Switched to Memory-Mapped I/O, added support for CT and Piggyback chips - 2022-December
;
; This code can be built with TASM Version 3.2:
;   tasm -70 -g3 -s dumper.asm dumper.bin
;
; Dumper code for all TMS7000 series parts
;
; Hardware connections:
;
; ~INT1 and ~INT3 wired to +5 - pins 13 and 12 on DIP
; Arduino can be written to by writing to any external memory address (code uses 0x1000)
; MC set to Vcc on startup by Arduino
; First write of 0x55 signals Arduino to flip MC from high to low
; Second write to Arduino is the ChipID byte
; Subsequent writes are dumps of Internal ROM
;   (length is dependant on the ChipID byte)
;
; When External Memory is enabled:
;
; Port B, bit 4 - Pin 38 on DIP - ALATCH
; Port B, bit 5 - Pin 1 on DIP  - R/~W 
; Port B, bit 6 - Pin 39 on DIP - ~ENABLE
; Port B, bit 7 - Pin 2 on DIP  - CLKOUT 
; Port C, all   - Address Low / Data Bus
; Port D, all*  - Address High Bus
; NOTE: Since the CT chips only have the upper 4 bits of Port D,
; We have mapped external memory such that every 4K block of TMS7000 space
; contains 16 copies of a single 256 byte block of the ROM chip
;
; Chip starts up in Microprocessor mode, executing ROM from external memory
; 1) Boots to 0x1000 - Code checks ram size and for presence of serial port, to generate initial ID byte
; 2) Trojan Code segment is copied from external ROM to internal RAM
; 3) Jump to code in internal RAM 
; 4) RAM-resident code sends Arduino a 0x55 to switch modes, enabling internal ROM
; 5) Jump back to external ROM
; 6) Code determines internal ROM size and adjusts ID byte
; 7) Code writes out bytes to Arduino:
;    ID byte, followed by internal ROM bytes

; RAM Layout
; 0x00-0x07 - A,B,R2-R7 Used as general purpose storage
; 0x08-0x18 - Reserved for Trojan program
; 0x19-0x7E - Spare
; 0x7F      - used to determine RAM size

; ID Byte bit definition:
;
; bit 0:    0 = No Serial Port, 1 = Serial Port detected
; bit 1:    0 = 128 bytes of RAM, 1 = 256 bytes of RAM
; bits 2-5: number of 2K blocks of Internal ROM present (0-8) = (0K-16K)
; bits 6-7: unused

;R0      .equ    0   ; AKA A Register
;R1      .equ    1   ; AKA B Register

R2      .equ    2   ; Used as a Counter variable
R3      .equ    3   ; Used for ID byte
R4      .equ    4   ; R4:R5 used as primary 2-byte Memory Index
R5      .equ    5
R6      .equ    6   ; R6:R7 used as secondary 2-byte Memory Index
R7      .equ    7

; peripherals

IOCNT0  .equ    0       ; Peripheral address to control CPU modes
ARDADDR .equ    $1000   ; Address to write a byte to the Arduino
SCTL1   .equ    21      ; Peripheral address to probe for a Serial Port on the 70x2
SCTL1C  .equ    24      ; Peripheral address to probe for a Serial Port on the 70Cx2
FDDR    .equ    $1F     ; Peripheral address to probe for Port F

RAMDEST .equ    $0008       ; location in ram for the code to be copied into and run from

; Binary image Layout:
; We fill 64K of space with this program, but we only use 4K of it in the ROM
; Each 4K block contains only 256 bytes of info

; 0x0X00 is unused.  The first 256 bytes will appear in the ROM

        .ORG    $0000       ; nothing here, fill with zeros
        .FILL   $100,$00

; 0x1X00 contains the code block.  Only 256 bytes are available.

        .ORG    $1000

        ; Initialize port, stack
START:
        MOV     %$0C,B      ; B  = 0C
        LDSP                ; SP = 000C - we don't use stack anyway
        MOVP    %$AA,IOCNT0 ; Disable some interrupts, set for Full Expansion mode after mode switch

        ; Try to identify this chip and store a code in R3
        MOV     %$00,R3     ; Initialize ID byte to 0, (128 bytes of RAM)

RAMCHK:
        ; Identify RAM size:
        ; do checks twice with different data,
        ; to protect against random luck matches

        MOV     %$55,$ff
        MOV     %$AA,$7f
        CMP     %$55,$ff    ; check for 256 bytes working
        JNZ     SERCHK      ; if fail, 128 bytes - jump to next step
        MOV     %$AA,$ff
        MOV     %$55,$7f
        CMP     %$AA,$ff    ; doublecheck for 256 bytes working
        JNZ     SERCHK      ; if fail, 128 bytes - jump to next step

RAM256:
        MOV     %$02,R3     ; We have 256 bytes or RAM

        ; Try to store bottom two bits of SCTL1 register and see if they "stay"
        ; if so, we have a UART
        ; We try both the locations, once for the 70X2 chip, and then the 70CX2 chip

SERCHK:
        ANDP    %$FC,SCTL1  ; zero the 2 LS bits
        MOVP    SCTL1,A
        AND     %$03,A
        JNZ     SERCHKC     ; fail if not zero
        ORP     %$01,SCTL1  ; set the bottom bit
        MOVP    SCTL1,A
        AND     %$03,A 
        CMP     %$01,A      ; check if it's a one now
        JNZ     SERCHKC     ; or fail
        ORP     %$02,SCTL1  ; set the next bit
        MOVP    SCTL1,A
        AND     %$03,A 
        CMP     %$03,A      ; should be 3 now
        JZ      SERFOUND    ; if not fail

SERCHKC:
        ANDP    %$FC,SCTL1C  ; zero the 2 LS bits
        MOVP    SCTL1C,A
        AND     %$03,A
        JNZ     CHKPORT      ; fail if not zero
        ORP     %$01,SCTL1C  ; set the bottom bit
        MOVP    SCTL1C,A
        AND     %$03,A 
        CMP     %$01,A       ; check if it's a one now
        JNZ     CHKPORT      ; or fail
        ORP     %$02,SCTL1C  ; set the next bit
        MOVP    SCTL1C,A
        AND     %$03,A 
        CMP     %$03,A       ; should be 3 now
        JNZ     CHKPORT      ; if not fail
SERFOUND:
        OR      %$01,R3      ; UART detected, set this bit

CHKPORT:
        ANDP    %$00,FDDR
        MOVP    FDDR,A
        JNZ     COPYCODE
        ORP     %$FF,FDDR
        MOVP    FDDR,A
        CMP     %$FF,A
        JNZ     COPYCODE
        OR      %$40,R3      ; Set bit 6 if this port exists

        ; Copy code from External ROM to RAM

COPYCODE:
        MOV     %$10,R2     ; Byte Counter - our code is < 16 bytes
        MOVD    %RAMCODE,R5 ; Start of ROM source
        MOVD    %RAMDEST,R7 ; Start of RAM destination
CPYLOOP:
        LDA     *R5         ; grab code byte
        STA     *R7         ; move code byte
        INC     R7          ; increment destination
        ADC     %$0,R6      ; ripple carry to high byte
        INC     R5          ; increment source
        ADC     %$0,R4      ; ripple carry to high byte
        DEC     R2          ; done yet?
        JNZ     CPYLOOP     ; if we are not done, loop to copy next byte
        ; our code copy to RAM is done
        BR      @RAMDEST    ; jump to code in RAM

; Start of code to be executed in RAM
; (Must be relocatable)
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

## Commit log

2022-10-15 Add some photos of Original board and some Databook pages
2022-10-19 added board and tweaked schematic for EPROM variants
    [dumper.kicad_pcb, dumper.kicad_sch]
2022-10-19 finished initial layout
    [dumper.kicad_pcb, dumper.kicad_sch]
2022-10-22 Simplified the schematic - no external writes needed
    [dumper.kicad_pcb, dumper.kicad_sch]
2022-10-22 Add stub for Arduino code
2022-10-22 updated board layout
    [dumper.kicad_pcb, dumper.kicad_sch]
2022-10-26 Arduino Code:
    Working!
    ASM Code changes:
    Use standard SPI, MSB First, compatible with default Arduino Uno SPI Slave
    Fill byte recommended to be FF
    2K image for 2716, instead of 8K DS1225Y
    Remove broken code to write to DS1225Y
    Add srec2bin tool
    [dumper.asm]
2022-10-29 Fix comments in assembly, Set Baud rate to 115200, Fix Checksum bug
    [dumper.asm]
2022-11-05 added button and LED, still need software support though
    [dumper.kicad_pcb, dumper.kicad_sch]
2022-11-20 Added support for new PCB, button, and LED
    Added Chip identification feature, improved user experience
    Fixed bug in byte counter in assembly code
    Add SRecWriter reset() API
    [dumper.asm]
2022-12-23 Update arduino software to use 0x01 for param instead of S*
    Change ChipID tag to remove problematic slash in filename
2022-12-23 Fix serial port detection on CMOS chips
    [dumper.asm]
2022-12-23 Update arduino code to detect NMOS vs CMOS
    Update arduino code to fix overflow issue with 256 bytes of RAM
2022-12-23 Remove specifics about chip numbers - handle on the arduino side
2022-12-23 Handle dumps of 8K and 12K chips
    Streamline nmos/cmos handling
    Using arduino String class now
2022-12-23 Move/rename Arduino project
2022-12-23 added gerbers
    [dumper-B_Cu.gbl, dumper-B_Mask.gbs, dumper-B_Paste.gbp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]
2022-12-23 added version B changes
    silk update and analog sense wire
    [dumper.kicad_pcb, dumper.kicad_sch]
2022-12-24 fixed resistor value for LED
    [dumper.kicad_pcb, dumper.kicad_sch]
2022-12-27 added plcc44 adapter
    [tms7000 plcc adapter.kicad_pcb, tms7000 plcc adapter.kicad_sch]
2022-12-27 added 0.7" pitch header adapter
    [tms7000 n2l adapter.kicad_pcb, tms7000 n2l adapter.kicad_sch]
2022-12-31 added gerbers for PLCC and 1.78mm pitch dip adapter
    [tms7000 n2l adapter-B_Cu.gbl, tms7000 n2l adapter-B_Mask.gbs, tms7000 n2l adapter-B_Paste.gbp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]
2022-12-31 Relocate code to E000 (temporary, wont work with chips with >4K of internal ROM)
    Jump to RAM for mode switch, then jump back to external ROM. Seems to work.
    Note: Staying in external ROM during mode switch seems to NOT work.
    [dumper.asm]
2022-12-31 First cut at changes needed for CT-compatible dumper
    TBD: extra port detection, comments
2022-12-31 Update dumper to memory-mapped I/O version
    TBD extra port detection pins
    [dumper.kicad_sch]
2023-01-07 Updates for memory-mapped IO
    [dumper.kicad_sch]
2023-01-10 laid out rev b dumper
    juggled all the address lines and additional arduino wiring to facilitate parallel reads and CT dumping
    [dumper.kicad_pcb, dumper.kicad_sch]
2023-01-11 added 28 pin adapter
    [tms7000 28 pin adapter.kicad_pcb, tms7000 28 pin adapter.kicad_sch]
2023-01-11 renamed plcc to plcc44 and added plcc68 adapter
    [tms7000 plcc 44 adapter.kicad_pcb, tms7000 plcc 44 adapter.kicad_sch, tms7000 plcc 68 adapter.kicad_pcb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]
2023-01-14 fixed plcc88, added qfp60, dip54, dip64, and dip64 small pitch
    [tms7000 54 pin adapter.kicad_pcb, tms7000 54 pin adapter.kicad_sch, tms7000 64 pin adapter.kicad_pcb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]
2023-01-28 Fixup bus cycles to work on all variations of chips.
    Skip dumps for now
    [dumper7k.ino]
2023-01-31 added gerbers for all adapters
    [dumper-B_Cu.gbl, dumper-B_Mask.gbs, dumper-B_Paste.gbp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]
2023-02-11 Use port F to detect C08 and C48 chips
    Add activity messages to avoid confusion due to startup time
    Fix NMOS/CMOS detection
    [dumper.asm, dumper7k.ino]
2023-03-07 added QFP adapter
    [tms7000 qfp 64 adapter.kicad_pcb, tms7000 qfp 64 adapter.kicad_sch]
2024-04-02 Bring in stuff from the main branch under xxx_old, Rev A
    [dumper-B_Cu.gbl, dumper-B_Mask.gbs, dumper-B_Paste.gbp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]
2024-04-02 updated qfp64 for fab
    [tms7000 qfp 64 adapter.kicad_pcb, tms7000 qfp 64 adapter.kicad_sch]
2024-04-02 added soic mousebites adapter
    [SOIC mousebites adapter.kicad_pcb, SOIC mousebites adapter.kicad_sch]
2024-04-02 updated for fab
    [SOIC mousebites adapter.kicad_pcb]
2024-04-25 opened in kicad 8
